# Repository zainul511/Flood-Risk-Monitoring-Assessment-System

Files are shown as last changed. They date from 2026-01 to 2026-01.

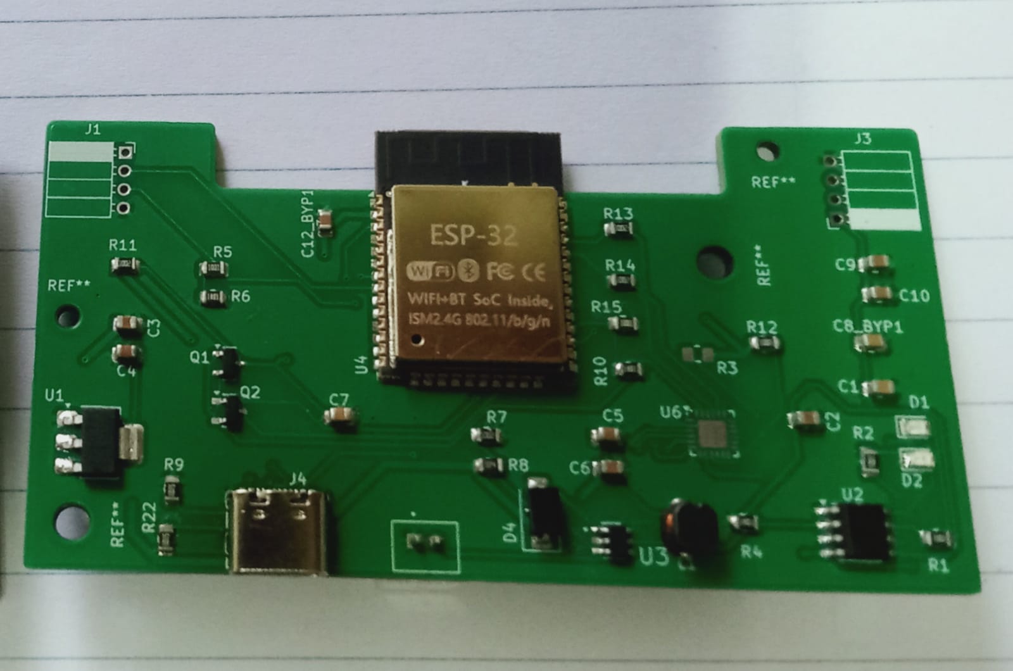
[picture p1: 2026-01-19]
Hardware/data-unit/docs/data-unit_soldered.jpeg

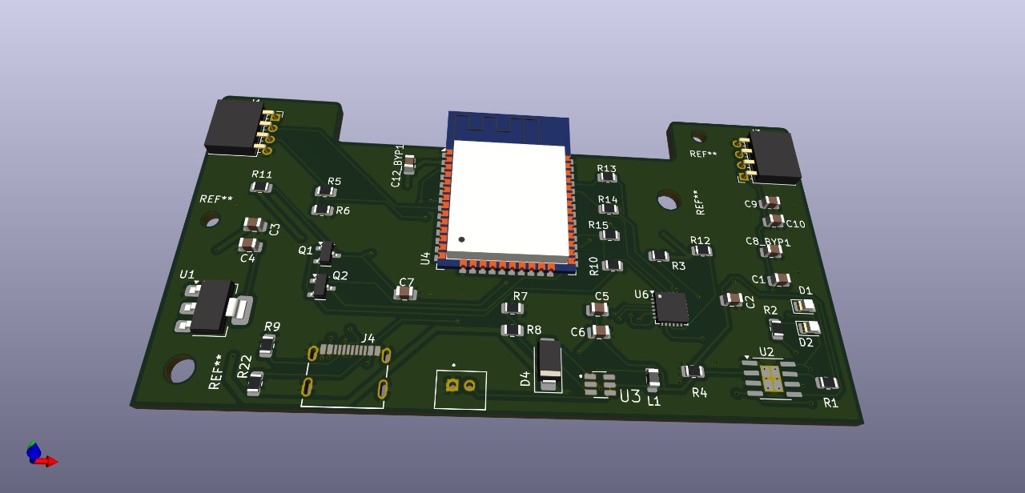
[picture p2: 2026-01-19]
Hardware/data-unit/docs/data-unit_3d.jpg

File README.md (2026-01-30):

# Flood Early Warning System

An IoT-based flood early warning system using ESP32 and wireless communication to monitor real-time water levels, generate alerts, and provide live dashboard visualization.

---

## Abstract
This project implements a real-time Flood Early Warning System using ESP32-based sensor nodes and a centralized controller unit. Water level data is measured using ultrasonic sensors and transmitted wirelessly using ESP-NOW. The controller unit evaluates risk levels, generates visual and audible alerts, and hosts a real-time web dashboard for monitoring.

---

## Problem Statement
Flood disasters often occur due to the absence of real-time, localized monitoring and early warning mechanisms. A low-cost, scalable, and wireless solution is required to provide timely flood alerts based on actual water level measurements.

---

## Objectives
- To design a real-time flood monitoring system using IoT
- To acquire water level data from remote locations
- To transmit data wirelessly with low latency
- To evaluate flood risk levels centrally
- To provide real-time alerts and dashboard visualization

---

## Features
- Real-time water level sensing
- ESP-NOW based low-latency wireless communication
- Centralized controller with alert logic
- LED and buzzer based warning system
- Live web-based monitoring dashboard
- Modular design scalable to multiple sensor nodes
- Custom-designed PCBs and enclosures

---

## System Overview
The system consists of:
- **Data Unit (Transmitter):** Measures water level and sends data wirelessly  
- **Controller Unit (Receiver):** Receives data, evaluates risk, triggers alerts, and hosts the dashboard  

---

## Hardware Used

### Controller Unit
- ESP32-C3 microcontroller
- LED indicators (Safe / Warning / Danger)
- Buzzer for audible alerts
- Power management and battery charging circuit
- Custom PCB and enclosure

### Data Unit (Sub-Unit)
- ESP32 microcontroller
- Ultrasonic water level sensor (HC-SR04 type)
- Power management and battery charging circuit
- Custom PCB and enclosure

---

## Firmware

### Communication Protocol
- **ESP-NOW** for sensor data transmission
- Fixed Wi-Fi channel for reliable communication
- One-to-one communication (extendable to multi-node)

### Transmitter (Data Unit)
- Measures water level using ultrasonic sensor
- Sends distance data periodically via ESP-NOW

**Libraries Used:**
- `WiFi.h`
- `esp_now.h`
- `esp_wifi.h`

### Receiver (Controller Unit)
- Receives sensor data via ESP-NOW
- Determines flood risk level
- Controls LEDs and buzzer
- Hosts a real-time web dashboard

**Libraries Used:**
- `WiFi.h`
- `esp_now.h`
- `esp_wifi.h`
- `WebServer.h`

---

## How It Works
1. The data unit measures water level using an ultrasonic sensor  
2. Measured distance is transmitted wirelessly via ESP-NOW  
3. The controller unit receives the data and evaluates risk levels  
4. LEDs and buzzer indicate Safe, Warning, or Danger conditions  
5. A web dashboard displays real-time distance and alert status  

---

## Real-Time Dashboard
The controller unit hosts a built-in web server that provides:
- Live water level display
- Flood status indication (Safe / Warning / Danger)
- Real-time distance trend graph

---

## Getting Started

### Prerequisites
- Arduino IDE
- ESP32 board package installed
- Two ESP32 boards (Data Unit & Controller Unit)

### Steps
1. Clone this repository
2. Upload `data_unit.ino` to the data unit ESP32
3. Upload `controller_unit.ino` to the controller unit ESP32
4. Configure Wi-Fi credentials in the controller firmware
5. Power both units
6. Access the dashboard using the controller’s IP address

---

## Demonstration
The system was successfully demonstrated by sensing real-time water level changes, transmitting data wirelessly, visualizing data on a live dashboard, and generating alerts based on predefined thresholds.

---

## Applications
- Flood early warning systems
- Disaster management
- Smart water monitoring
- Environmental sensing networks

---

## License
This project is licensed under the **MIT License**.

## Contributors

- [Ahamed Hathi](https://github.com/ahamedhathi2002-ux)
- [Zainul Hussain](https://github.com/zainul511)
- [Mohomed Sahmi](https://github.com/sahmi344)

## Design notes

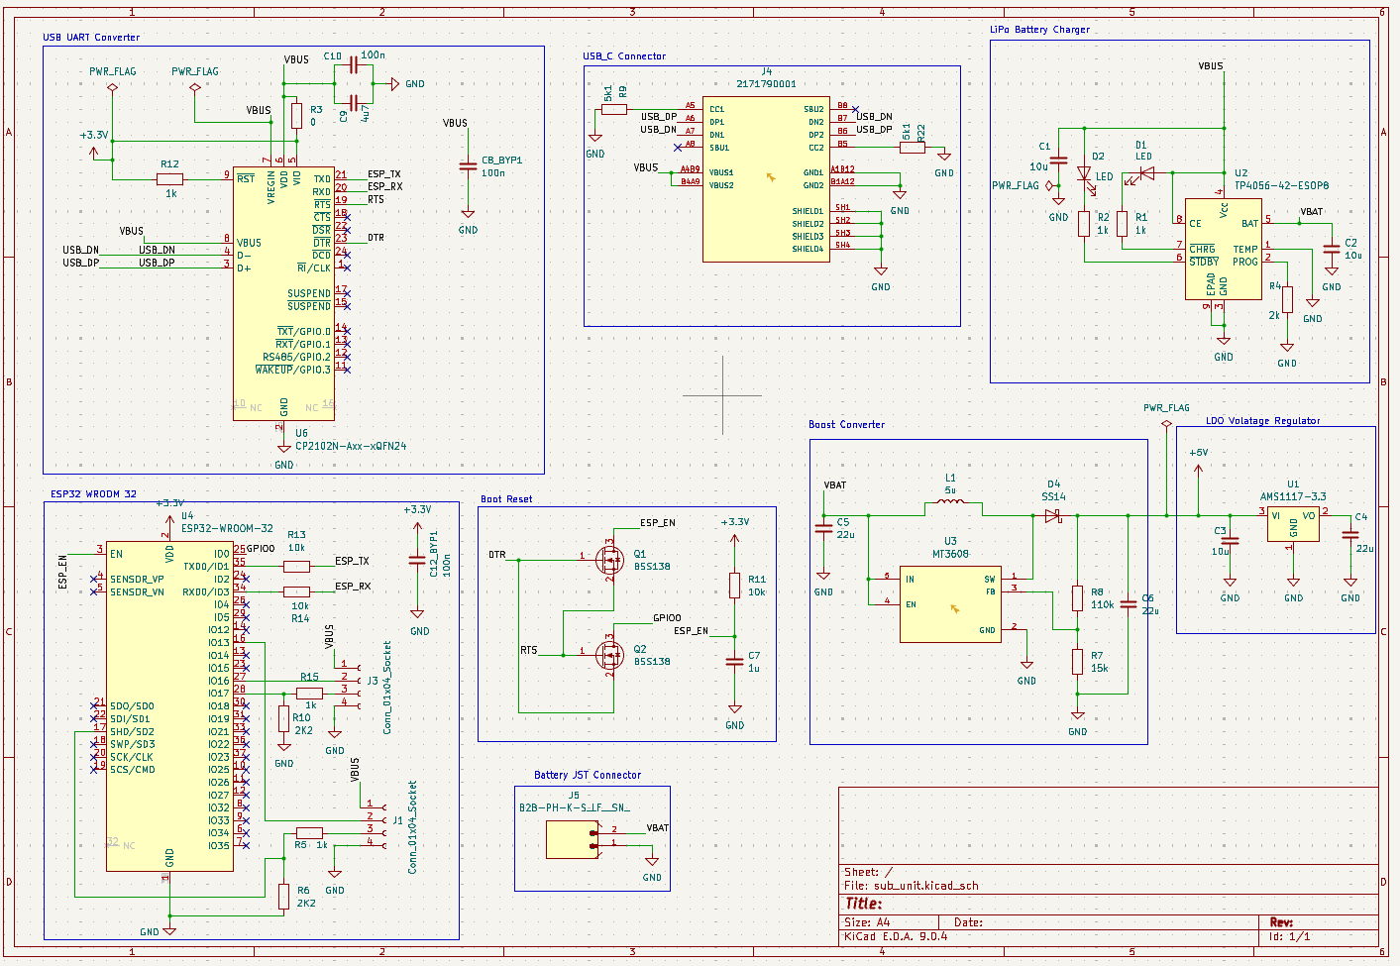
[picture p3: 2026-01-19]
Hardware/data-unit/docs/data-unit_schematic.PNG

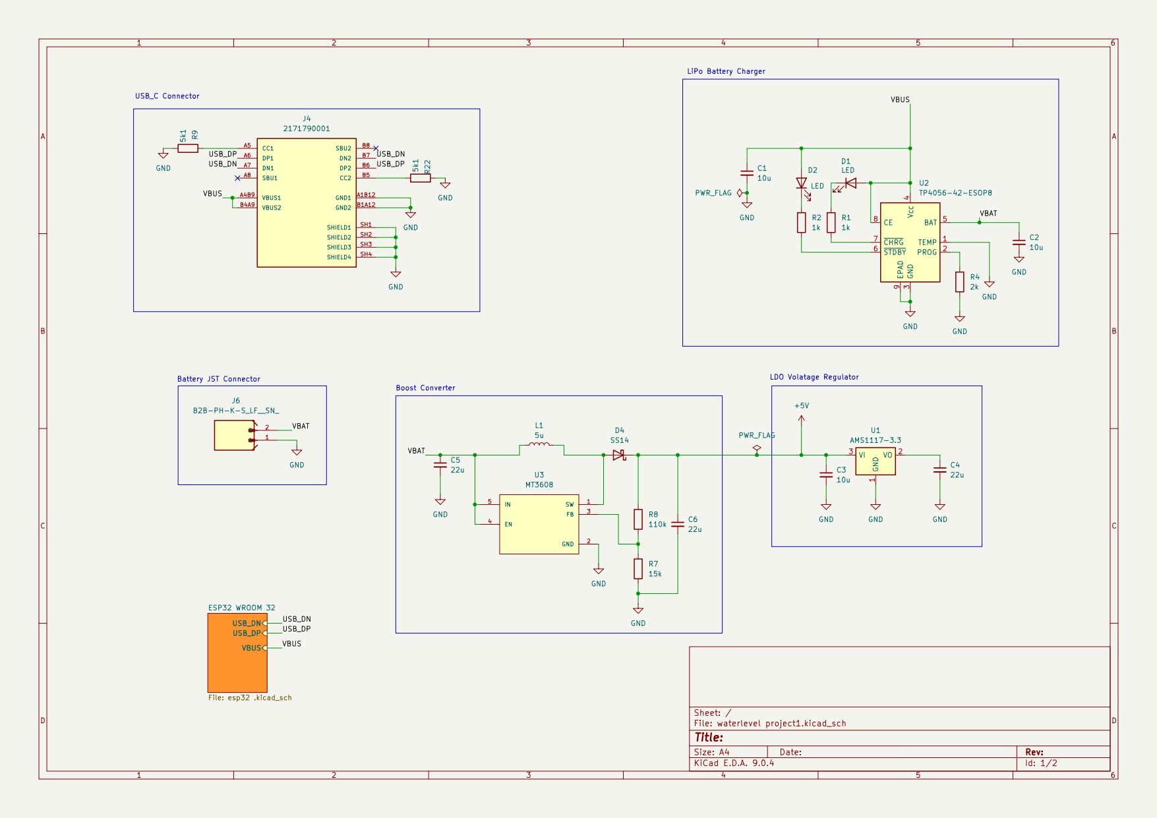
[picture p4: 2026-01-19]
Hardware/controller_unit/docs/controller_unit_schematic_page-0001.jpg

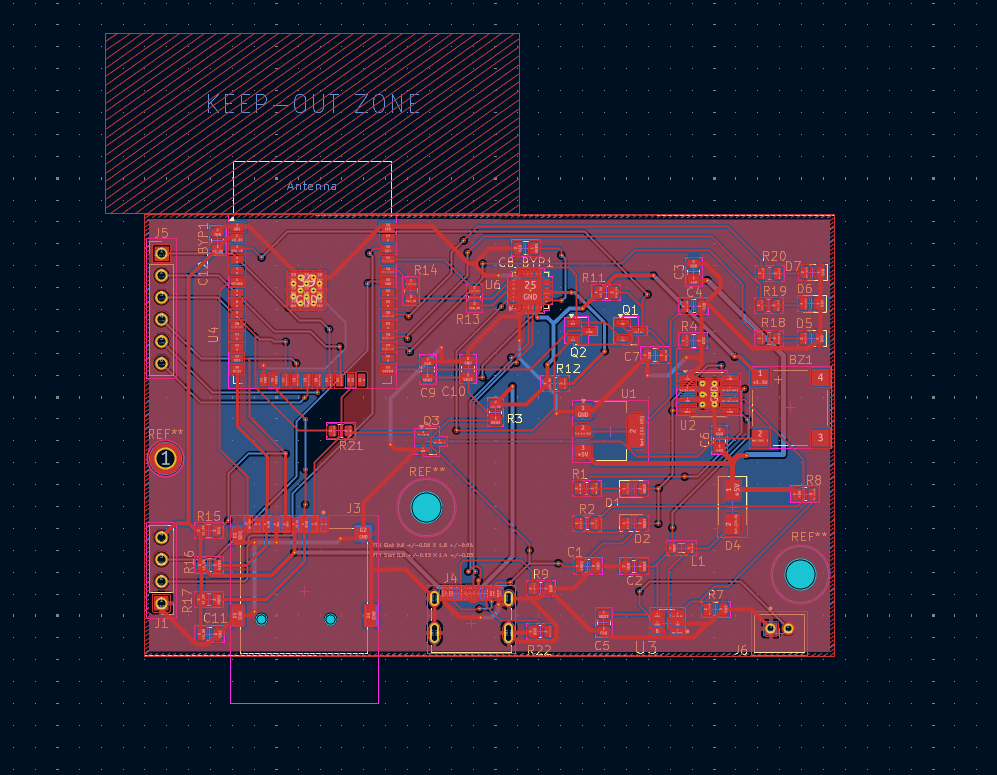
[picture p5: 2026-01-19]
Hardware/controller_unit/docs/controller_unit_layout.PNG

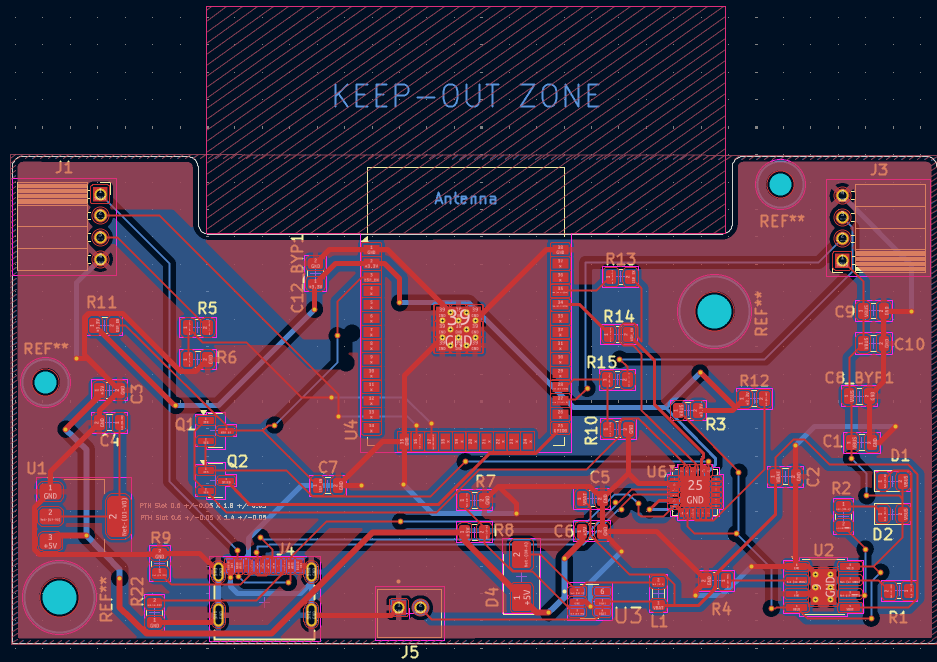
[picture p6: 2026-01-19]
Hardware/data-unit/docs/data-unit_layout.PNG

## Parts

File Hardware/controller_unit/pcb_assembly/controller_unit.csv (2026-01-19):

Reference | Qty | Value | DNP | Exclude from BOM | Exclude from Board | Footprint | Datasheet
BZ1 | 1 | Buzzer |  |  |  | Buzzer_Beeper:PUIAudio_SMT_0825_S_4_R | ~
C1,C2,C3 | 3 | 10u |  |  |  | Capacitor_SMD:C_0805_2012Metric | ~
C4,C5,C6 | 3 | 22u |  |  |  | Capacitor_SMD:C_0805_2012Metric | ~
C7 | 1 | 1u |  |  |  | Capacitor_SMD:C_0805_2012Metric | ~
C8_BYP1,C10,C12_BYP1 | 3 | 100n |  |  |  | Capacitor_SMD:C_0805_2012Metric | ~
C9 | 1 | 4u7 |  |  |  | Capacitor_SMD:C_0805_2012Metric | ~
C11 | 1 | 0.1u |  |  |  | Capacitor_SMD:C_0805_2012Metric | ~
D1,D2,D5,D6,D7 | 5 | LED |  |  |  | LED_SMD:LED_0805_2012Metric | ~
D4 | 1 | SS14 |  |  |  | Diode_SMD:D_SMA | https://www.vishay.com/docs/88746/ss12.pdf
J1 | 1 | Conn_01x04_Pin |  |  |  | Connector_PinHeader_2.54mm:PinHeader_1x04_P2.54mm_Vertical | ~
J3 | 1 | MSD-4-A |  |  |  | New_Library3:CUI_MSD-4-A
J4 | 1 | 2171790001 |  |  |  | New_Library4:MOLEX_2171790001
J5 | 1 | Conn_01x06_Pin |  |  |  | Connector_PinHeader_2.54mm:PinHeader_1x06_P2.54mm_Vertical | ~
J6 | 1 | B2B-PH-K-S_LF__SN_ |  |  |  | NewLibrary6:JST_B2B-PH-K-S_LF__SN_
L1 | 1 | 5u |  |  |  | Inductor_SMD:L_0805_2012Metric | ~
Q1,Q2 | 2 | BSS138 |  |  |  | Package_TO_SOT_SMD:SOT-23 | https://www.onsemi.com/pub/Collateral/BSS138-D.PDF
Q3 | 1 | BC847 |  |  |  | Package_TO_SOT_SMD:SOT-23 | http://www.infineon.com/dgdl/Infineon-BC847SERIES_BC848SERIES_BC849SERIES_BC850SERIES-DS-v01_01-en.pdf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
R1,R2,R12,R21 | 4 | 1k |  |  |  | Resistor_SMD:R_0805_2012Metric | ~
R3 | 1 | 0 |  |  |  | Resistor_SMD:R_0805_2012Metric | ~
R4 | 1 | 2k |  |  |  | Resistor_SMD:R_0805_2012Metric | ~
R7 | 1 | 15k |  |  |  | Resistor_SMD:R_0805_2012Metric | ~
R8 | 1 | 110k |  |  |  | Resistor_SMD:R_0805_2012Metric | ~
R9,R22 | 2 | 5k1 |  |  |  | Resistor_SMD:R_0805_2012Metric | ~
R11,R13,R14,R15,R16,R17 | 6 | 10k |  |  |  | Resistor_SMD:R_0805_2012Metric | ~
R18,R19,R20 | 3 | 150 |  |  |  | Resistor_SMD:R_0805_2012Metric | ~
U1 | 1 | AMS1117-3.3 |  |  |  | Package_TO_SOT_SMD:SOT-223-3_TabPin2 | http://www.advanced-monolithic.com/pdf/ds1117.pdf
U2 | 1 | TP4056-42-ESOP8 |  |  |  | Package_SO:SOIC-8-1EP_3.9x4.9mm_P1.27mm_EP2.41x3.3mm_ThermalVias | https://www.lcsc.com/datasheet/lcsc_datasheet_2410121619_TOPPOWER-Nanjing-Extension-Microelectronics-TP4056-42-ESOP8_C16581.pdf
U3 | 1 | MT3608 |  |  |  | New_Library1:SOT95P280X145-6N
U4 | 1 | ESP32-WROOM-32 |  |  |  | RF_Module:ESP32-WROOM-32 | https://www.espressif.com/sites/default/files/documentation/esp32-wroom-32_datasheet_en.pdf
U6 | 1 | CP2102N-Axx-xQFN24 |  |  |  | Package_DFN_QFN:QFN-24-1EP_4x4mm_P0.5mm_EP2.6x2.6mm | https://www.silabs.com/documents/public/data-sheets/cp2102n-datasheet.pdf

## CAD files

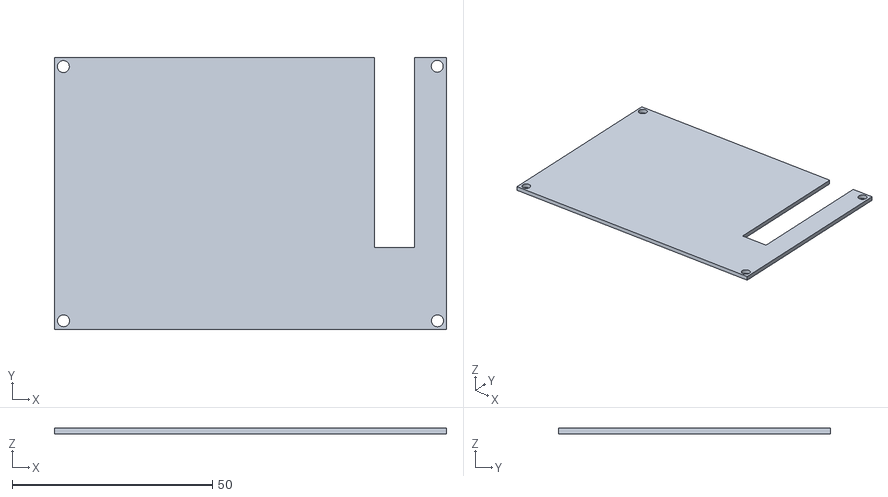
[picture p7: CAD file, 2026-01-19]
Enclosure 3D Models/controller_unit enclosure/LID Main Unit.stl
98.0 x 68.0 x 1.40

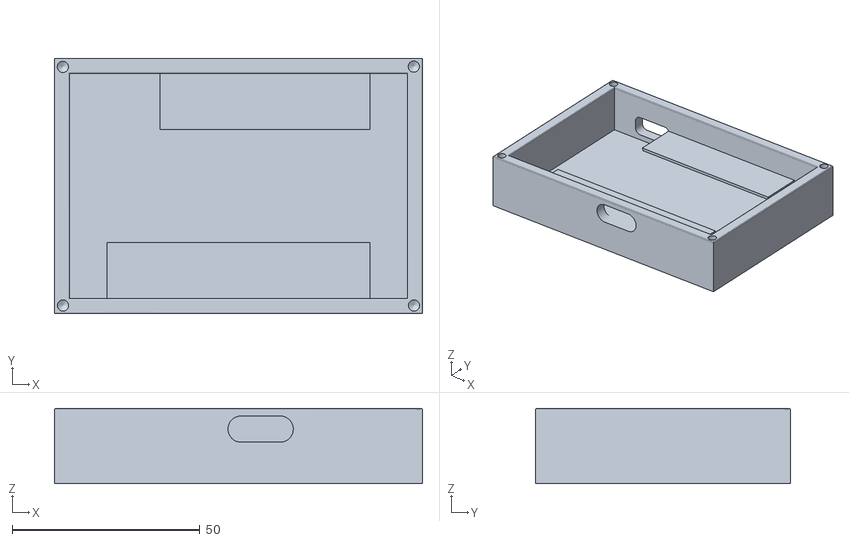
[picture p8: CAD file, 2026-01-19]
Enclosure 3D Models/controller_unit enclosure/Main Unit.stl
98.0 x 68.0 x 20.0

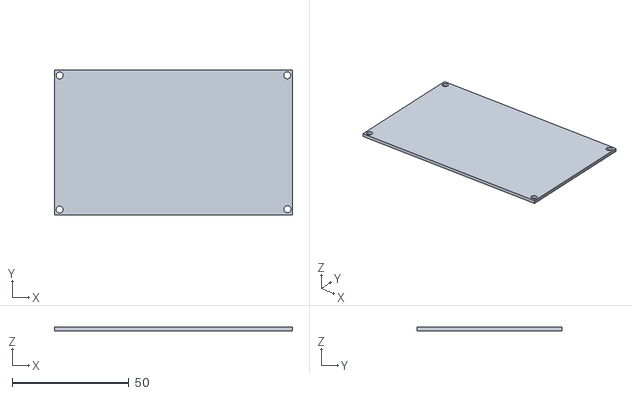
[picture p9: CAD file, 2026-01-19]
Enclosure 3D Models/data_unit enclosure/Sub Unit LID.stl
102.0 x 62.0 x 1.50

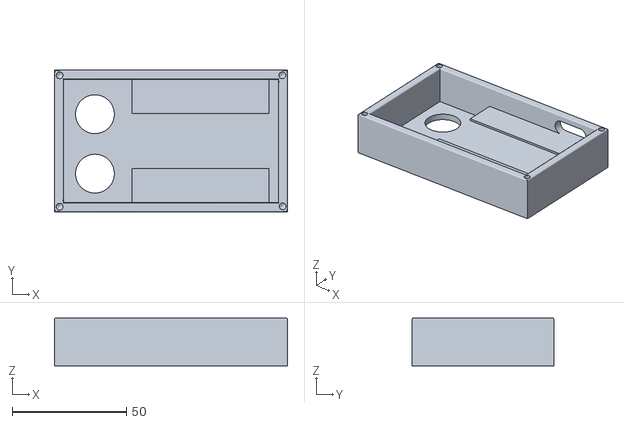
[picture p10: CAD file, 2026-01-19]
Hardware/data-unit/enclosure/data-unit.stl
102.0 x 62.0 x 21.0

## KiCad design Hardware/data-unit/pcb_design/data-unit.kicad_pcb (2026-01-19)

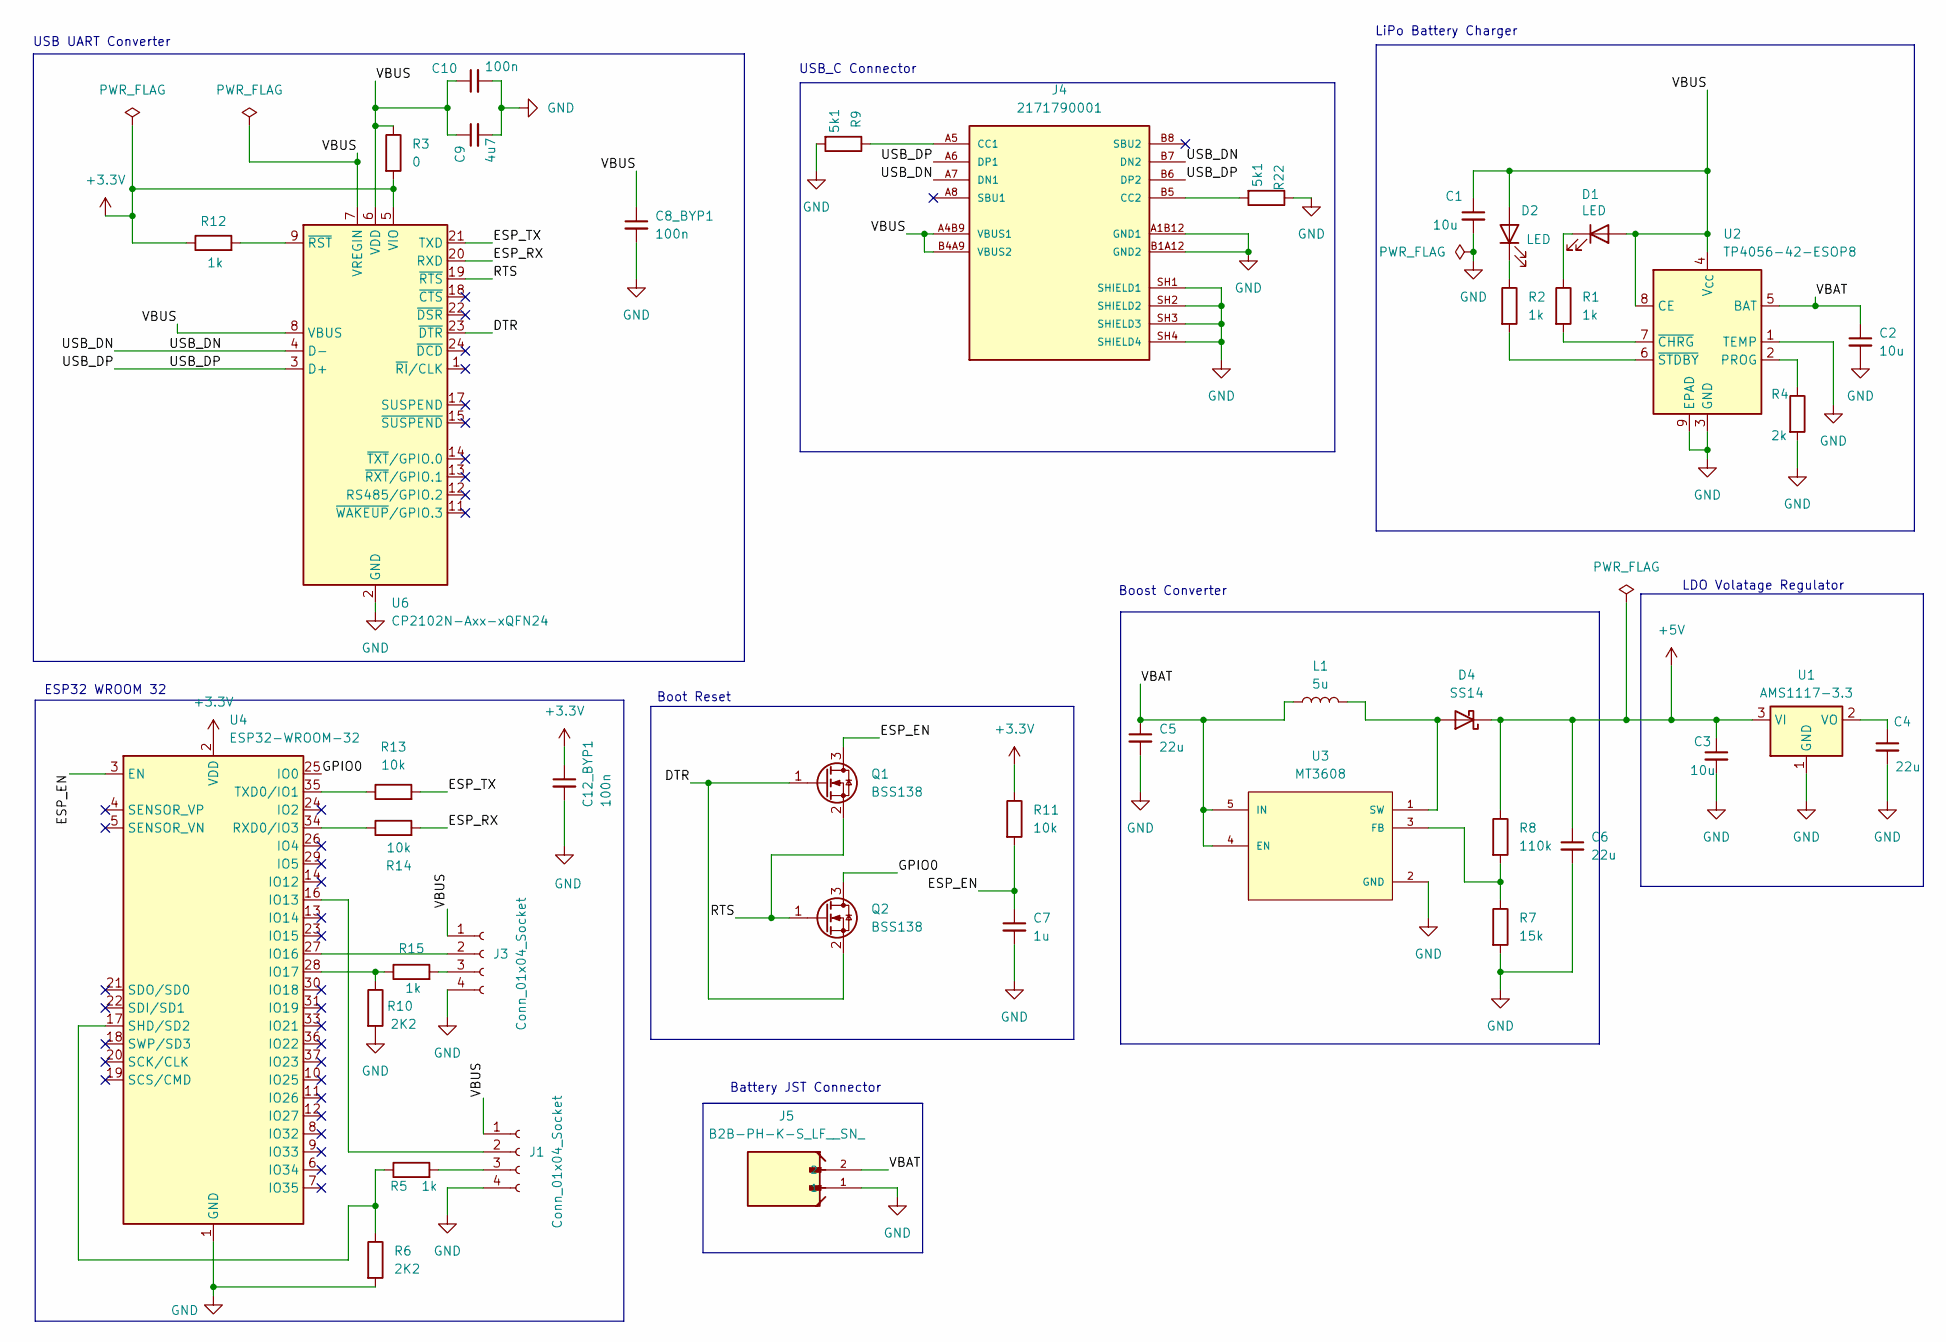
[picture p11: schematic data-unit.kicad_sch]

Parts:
C1, C2, C3: 10u; C_0805_2012Metric
C4, C5, C6: 22u; C_0805_2012Metric
C7: 1u; C_0805_2012Metric
C8_BYP1, C10, C12_BYP1: 100n; C_0805_2012Metric
C9: 4u7; C_0805_2012Metric
D1, D2: LED; LED_0805_2012Metric
D4: SS14; D_SMA
J1, J3: Conn_01x04_Socket; PinSocket_1x04_P2.00mm_Horizontal
J4: 2171790001; MOLEX_2171790001; PARTREV A1
J5: B2B-PH-K-S_LF__SN_; JST_B2B-PH-K-S_LF__SN_
L1: 5u; L_0805_2012Metric
Q1, Q2: BSS138; SOT-23
R1, R2, R5, R12, R15: 1k; R_0805_2012Metric
R3: 0; R_0805_2012Metric
R4: 2k; R_0805_2012Metric
R6, R10: 2K2; R_0805_2012Metric
R7: 15k; R_0805_2012Metric
R8: 110k; R_0805_2012Metric
R9, R22: 5k1; R_0805_2012Metric
R11, R13, R14: 10k; R_0805_2012Metric
U1: AMS1117-3.3; SOT-223-3_TabPin2
U2: TP4056-42-ESOP8; SOIC-8-1EP_3.9x4.9mm_P1.27mm_EP2.41x3.3mm_ThermalVias
U3: MT3608; SOT95P280X145-6N; PARTREV 1.0
U4: ESP32-WROOM-32
U6: CP2102N-Axx-xQFN24; QFN-24-1EP_4x4mm_P0.5mm_EP2.6x2.6mm

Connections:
+3.3V: C12_BYP1.1, R3.2, R11.1, R12.1, U4.2 (VDD), U6.5 (VIO)
+5V: C3.1, C6.1, D4.1 (K), R8.1, U1.3 (VI)
/DTR: Q1.1 (G), Q2.2 (S), U6.23 (~DTR)
/ESP_EN: C7.1, Q1.3 (D), R11.2, U4.3 (EN)
/ESP_RX: R14.2, U6.20 (RXD)
/ESP_TX: R13.2, U6.21 (TXD)
/GPIO0: Q2.3 (D), U4.25 (IO0)
/RTS: Q1.2 (S), Q2.1 (G), U6.19 (~RTS)
/USB_DN: J4.A7 (DN1), J4.B7 (DN2), U6.4 (D-)
/USB_DP: J4.A6 (DP1), J4.B6 (DP2), U6.3 (D+)
/VBAT: C2.1, C5.1, J5.2, L1.1, U2.5 (BAT), U3.4 (EN), U3.5 (IN)
/VBUS: C1.1, C8_BYP1.1, C9.1, C10.1, D1.2 (A), D2.2 (A), J1.1, J3.1, J4.A4B9 (VBUS1), J4.B4A9 (VBUS2), R3.1, U2.4 (V_{CC}), U2.8 (CE), U6.6 (VDD), U6.7 (VREGIN), U6.8 (VBUS)
GND: C1.2, C2.2, C3.2, C4.2, C5.2, C6.2, C7.2, C8_BYP1.2, C9.2, C10.2, C12_BYP1.2, J1.4, J3.4, J4.A1B12 (GND1), J4.B1A12 (GND2), J4.SH1 (SHIELD1), J4.SH2 (SHIELD2), J4.SH3 (SHIELD3), J4.SH4 (SHIELD4), J5.1, R4.2, R6.2, R7.2, R9.2, R10.2, R22.1, U1.1 (GND), U2.1 (TEMP), U2.3 (GND), U2.9 (EPAD), U3.2 (GND), U4.1 (GND), U4.15 (GND), U4.38 (GND), U4.39 (GND), U6.2 (GND), U6.25 (GND)
unnamed: D1.1 (K), R1.1
unnamed: D2.1 (K), R2.1
unnamed: D4.2 (A), L1.2, U3.1 (SW)
unnamed: J1.2, U4.16 (IO13)
unnamed: J1.3, R5.2
unnamed: J3.2, U4.27 (IO16)
unnamed: J3.3, R15.2
unnamed: J4.A5 (CC1), R9.1
unnamed: J4.B5 (CC2), R22.2
unnamed: C4.1, U1.2 (VO)
unnamed: R4.1, U2.2 (PROG)
unnamed: R1.2, U2.7 (~CHRG)
unnamed: R2.2, U2.6 (~STDBY)
unnamed: R7.1, R8.2, U3.3 (FB)
unnamed: R10.1, R15.1, U4.28 (IO17)
unnamed: R14.1, U4.34 (RXD0/IO3)
unnamed: R5.1, R6.1, U4.17 (SHD/SD2)
unnamed: R13.1, U4.35 (TXD0/IO1)
unnamed: R12.2, U6.9 (~RST)

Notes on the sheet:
Boot Reset
USB UART Converter
ESP32 WROOM 32
USB_C Connector
LiPo Battery Charger
Battery JST Connector
Boost Converter
LDO Volatage Regulator

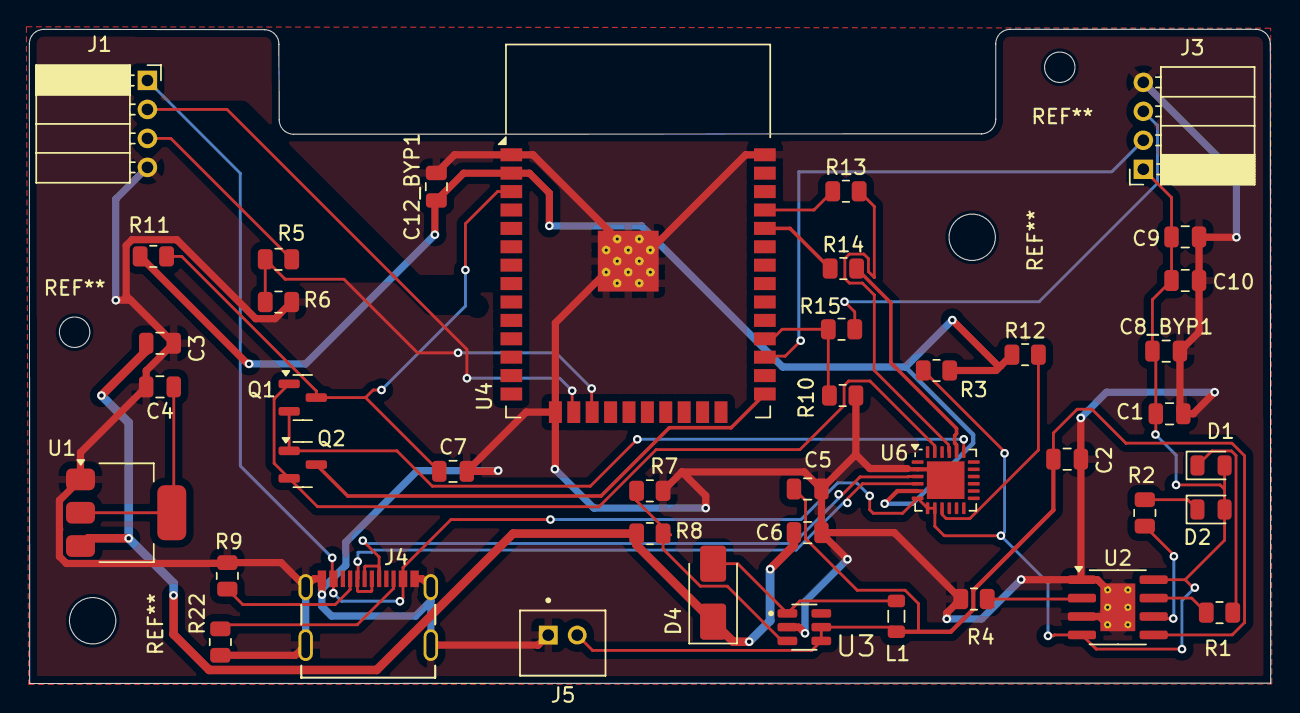
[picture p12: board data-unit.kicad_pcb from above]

Board: 2 copper layers, 85.7 x 45.1 mm, 42 parts (0 on the bottom side), 32 nets.

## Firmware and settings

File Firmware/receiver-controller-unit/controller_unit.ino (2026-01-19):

#include <WiFi.h>
#include <esp_now.h>
#include <WebServer.h>
#include <esp_wifi.h>


/* ================= WiFi ================= */
const char* ssid = "Galaxy";
const char* password = "sahmi123";

/* ================= LED PINS (ESP32-C3 SAFE) ================= */
#define LED_SAFE    9   // >20 cm
#define LED_WARN    7   // 10–20 cm
#define LED_DANGER  2   // <10 cm
#define buzzer      5



/* ================= WEB SERVER ================= */
WebServer server(80);

/* ================= ESP-NOW STRUCT ================= */
typedef struct {
  float distance;
} struct_message;

struct_message myData;
float lastDistance = 0.0;

/* ================= ESP-NOW RECEIVE ================= */
void OnDataRecv(const esp_now_recv_info *info,
                const uint8_t *incomingData,
                int len) {
  memcpy(&myData, incomingData, sizeof(myData));
  lastDistance = myData.distance;

  Serial.print("Received distance: ");
  Serial.println(lastDistance);

  if (lastDistance > 20) {
    digitalWrite(LED_SAFE, HIGH);
    digitalWrite(LED_WARN, LOW);
    digitalWrite(LED_DANGER, LOW);
    digitalWrite(buzzer, LOW);

  } else if (lastDistance > 10) {
    digitalWrite(LED_SAFE, LOW);
    digitalWrite(LED_WARN, HIGH);
    digitalWrite(LED_DANGER, LOW);
    digitalWrite(buzzer, LOW);
    
  } else {
    digitalWrite(LED_SAFE, LOW);
    digitalWrite(LED_WARN, LOW);
    digitalWrite(LED_DANGER, HIGH);
    digitalWrite(buzzer, HIGH);
    
  }
}

/* ================= JSON DATA ================= */
void handleData() {
  String json = "{\"distance\":" + String(lastDistance, 2) + "}";
  server.send(200, "application/json", json);
}

/* ================= DASHBOARD ================= */
void handleRoot() {
  server.send(200, "text/html", R"rawliteral(
<!DOCTYPE html>
<html>
<head>
<meta charset="utf-8">
<title>Flood Monitoring Dashboard</title>

<!-- Icons -->
<link rel="stylesheet" href="https://cdnjs.cloudflare.com/ajax/libs/font-awesome/6.4.0/css/all.min.css">

<!-- Chart.js -->
<script src="https://cdn.jsdelivr.net/npm/chart.js"></script>

<style>
body{
  margin:0;
  font-family: 'Segoe UI', Arial, sans-serif;
  background: linear-gradient(135deg,#0f2027,#203a43,#2c5364);
  color:#fff;
}

.header{
  padding:20px;
  text-align:center;
  background:rgba(0,0,0,0.3);
  box-shadow:0 4px 10px rgba(0,0,0,0.4);
}

.container{
  max-width:900px;
  margin:30px auto;
  padding:20px;
}

.cards{
  display:grid;
  grid-template-columns:repeat(auto-fit,minmax(250px,1fr));
  gap:20px;
}

.card{
  background:rgba(255,255,255,0.1);
  border-radius:15px;
  padding:20px;
  box-shadow:0 8px 20px rgba(0,0,0,0.4);
  text-align:center;
}

.card i{
  font-size:40px;
  margin-bottom:10px;
}

.value{
  font-size:2.8rem;
  font-weight:bold;
}

.status{
  margin-top:10px;
  font-size:1.4rem;
  font-weight:bold;
}

.safe{color:#00ff88;}
.warn{color:#ffb300;}
.danger{color:#ff4c4c;}

.chart-card{
  margin-top:30px;
  background:#fff;
  border-radius:15px;
  padding:20px;
  color:#000;
}

.footer{
  text-align:center;
  padding:15px;
  opacity:0.7;
  font-size:0.9rem;
}
</style>
</head>

<body>

<div class="header">
  <h1>🌊 Flood Monitoring System</h1>
  <p>Real-time Water Level Monitoring</p>
</div>

<div class="container">

  <div class="cards">
    <div class="card">
      <i class="fa-solid fa-ruler-vertical"></i>
      <div class="value" id="distance">-- cm</div>
      <div>Water Distance</div>
    </div>

    <div class="card">
      <i class="fa-solid fa-triangle-exclamation"></i>
      <div class="status" id="zone">---</div>
      <div>Alert Status</div>
    </div>
  </div>

  <div class="chart-card">
    <h3>Distance Trend</h3>
    <canvas id="chart"></canvas>
  </div>

</div>

<div class="footer">
  ESP32-C3 | ESP-NOW | IoT Flood Monitoring
</div>

<script>
let ctx=document.getElementById('chart').getContext('2d');
let chart=new Chart(ctx,{
  type:'line',
  data:{
    labels:[],
    datasets:[{
      label:'Distance (cm)',
      data:[],
      borderColor:'#0077ff',
      backgroundColor:'rgba(0,119,255,0.2)',
      tension:0.4,
      fill:true
    }]
  },
  options:{
    responsive:true,
    scales:{
      y:{beginAtZero:true}
    }
  }
});

async function updateData(){
  let r=await fetch('/data');
  let j=await r.json();
  let d=j.distance;

  document.getElementById('distance').innerText=d.toFixed(2)+" cm";

  let z=document.getElementById('zone');
  z.className="status";

  if(d>20){
    z.innerText="SAFE";
    z.classList.add("safe");
  }else if(d>10){
    z.innerText="WARNING";
    z.classList.add("warn");
  }else{
    z.innerText="DANGER";
    z.classList.add("danger");
  }

  let t=new Date().toLocaleTimeString();
  chart.data.labels.push(t);
  chart.data.datasets[0].data.push(d);

  if(chart.data.labels.length>25){
    chart.data.labels.shift();
    chart.data.datasets[0].data.shift();
  }

  chart.update();
}

setInterval(updateData,1000);
</script>

</body>
</html>
)rawliteral");
}


/* ================= SETUP ================= */
void setup() {
  Serial.begin(115200);

  pinMode(LED_SAFE, OUTPUT);
  pinMode(LED_WARN, OUTPUT);
  pinMode(LED_DANGER, OUTPUT);
  pinMode(buzzer,OUTPUT);
  
  //pinMode(Buzzer,OUTPUT);

  /* ---- WiFi + ESP-NOW CHANNEL FIX ---- */
  WiFi.mode(WIFI_STA);

  // 🔥 LOCK CHANNEL (MUST MATCH TRANSMITTER)
  esp_wifi_set_channel(1, WIFI_SECOND_CHAN_NONE);

  // Now connect to WiFi
  WiFi.begin(ssid, password);

  Serial.print("Connecting to WiFi");
  while (WiFi.status() != WL_CONNECTED) {
    delay(500);
    Serial.print(".");
  }
  Serial.println("\nWiFi Connected");

  Serial.print("ESP32-C3 IP Address: ");
  Serial.println(WiFi.localIP());

  /* ---- ESP-NOW ---- */
  if (esp_now_init() != ESP_OK) {
    Serial.println("ESP-NOW Init Failed");
    return;
  }

  esp_now_register_recv_cb(OnDataRecv);
  Serial.println("ESP-NOW Receiver Ready");

  /* ---- WEB SERVER ---- */
  server.on("/", handleRoot);
  server.on("/data", handleData);
  server.begin();

  Serial.println("Web server started");
}

/* ================= LOOP ================= */
void loop() {
  server.handleClient();
}

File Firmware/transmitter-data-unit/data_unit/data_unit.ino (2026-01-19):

#include <WiFi.h>
#include <esp_now.h>
#include <esp_wifi.h>   // 🔥 REQUIRED for esp_wifi_set_channel()

#define TRIG_PIN 16
#define ECHO_PIN 17

typedef struct struct_message {
  float distance;
} struct_message;

struct_message myData;

// 🔁 Receiver MAC (ESP32-C3 Super Mini)
uint8_t receiverAddress[] = {0xD8, 0x3B, 0xDA, 0x34, 0xF1, 0x8C};

esp_now_peer_info_t peerInfo;

// Measure distance
float getDistance() {
  digitalWrite(TRIG_PIN, LOW);
  delayMicroseconds(2);
  digitalWrite(TRIG_PIN, HIGH);
  delayMicroseconds(10);
  digitalWrite(TRIG_PIN, LOW);

  long duration = pulseIn(ECHO_PIN, HIGH, 30000); // timeout added
  if (duration == 0) return -1;

  return duration * 0.0343 / 2;
}

// Send callback
void OnDataSent(const wifi_tx_info_t *info, esp_now_send_status_t status) {
  Serial.print("Send Status: ");
  Serial.println(status == ESP_NOW_SEND_SUCCESS ? "✅ Success" : "❌ Fail");
}

void setup() {
  Serial.begin(115200);

  pinMode(TRIG_PIN, OUTPUT);
  pinMode(ECHO_PIN, INPUT);

  // ✅ MUST SET SAME CHANNEL AS RECEIVER
  WiFi.mode(WIFI_STA);
  esp_wifi_set_channel(1, WIFI_SECOND_CHAN_NONE);  // 🔥 IMPORTANT

  Serial.print("Transmitter MAC: ");
  Serial.println(WiFi.macAddress());

  if (esp_now_init() != ESP_OK) {
    Serial.println("ESP-NOW Init Failed");
    return;
  }

  esp_now_register_send_cb(OnDataSent);

  // Add peer ONLY ONCE
  memset(&peerInfo, 0, sizeof(peerInfo));
  memcpy(peerInfo.peer_addr, receiverAddress, 6);
  peerInfo.channel = 1;      // 🔥 MUST MATCH
  peerInfo.encrypt = false;

  if (esp_now_add_peer(&peerInfo) != ESP_OK) {
    Serial.println("Failed to add peer");
    return;
  }

  Serial.println("ESP-NOW Transmitter Ready");
}

void loop() {
  myData.distance = getDistance();

  Serial.print("Distance: ");
  Serial.println(myData.distance);

  esp_now_send(receiverAddress, (uint8_t *)&myData, sizeof(myData));
  delay(1000);
}
